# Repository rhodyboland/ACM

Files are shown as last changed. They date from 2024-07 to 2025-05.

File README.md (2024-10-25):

# ACM V2
**Second generation of the ACM**

This device is intended to be a control module for accessories that have been fitted to a camping/touring/4wdriving oriented vehicle. These controllable accessories could be lighting, fridge, air commpressor, water pump, tv, and more. 
The device can take inputs from various sources and use internal logic to provide monitoring to the user.
The device is to be app controlled from a mobile phone.

### Hardware:
  - 3rd generation of custom PCB with high side switches from STM. Powered by ESP32-S3
    - STM High side switches with current sensing and auto disconnect
      - 2x VNQ9025AJTR Quad Channel 30A max
      - 1x VND9008AJTR Dual Channel 67A max
  - RGB LED WS2812B
  - ESP32-S3-WROOM1-N16R8
      - USB C Programming and debug
      - Reset and boot buttons
      - Auto selecting 12v or USB 5v 3v3 regulator
  - Inputs for 2 sensors and 2 12v switches/inputs
  - Outputs Term blocks
  - High current 12V input
  - CAN for expansion

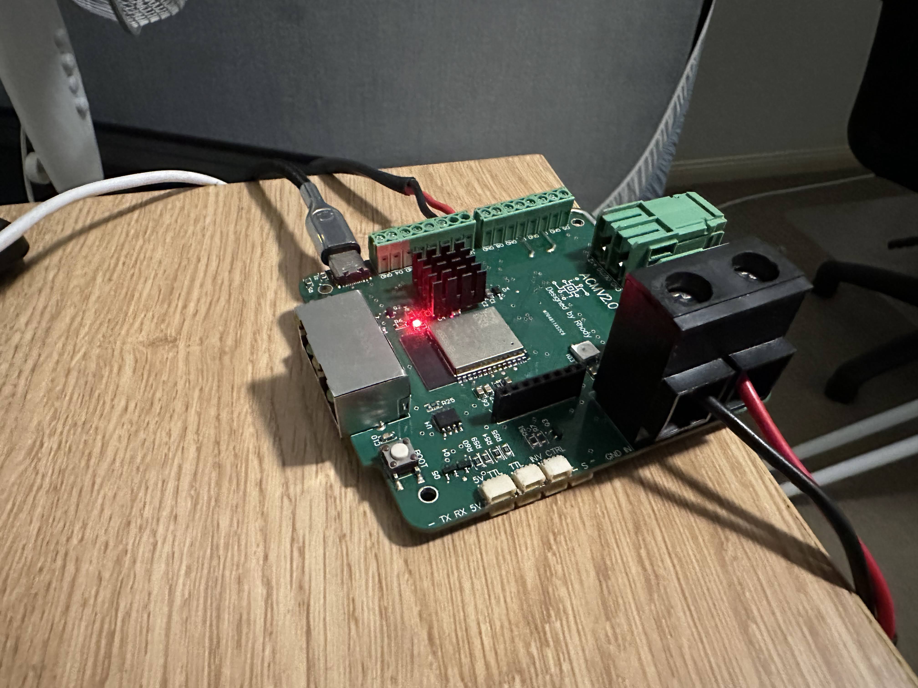
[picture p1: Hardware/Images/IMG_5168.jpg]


### Software:
#### Platform IO using arduino framework
  - BLE
#### Features (configurable in app)
- Switches for each channel
- Battery voltage and percentage
- Total and individual current measurement
- Auto cut-out of outputs for low battery voltage with priority selection and auto cut-in
- Power used and remaining
- Victron VE Serial input and parsing (MPPT etc.)
- JK BMS input.
- Low side switched inverter control (Highside uses standard out)
- Diagnostic outputs
- CAN to esp32 display coming

#### Custom IOS App ####

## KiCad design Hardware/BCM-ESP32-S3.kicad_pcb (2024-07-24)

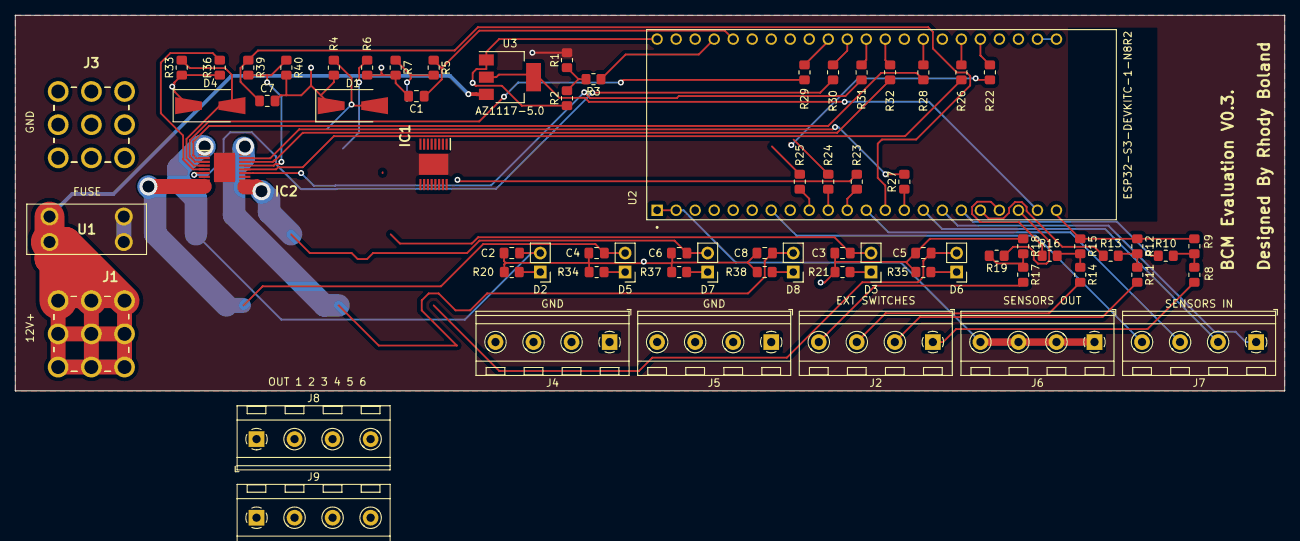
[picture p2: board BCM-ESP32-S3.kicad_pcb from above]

Board: 2 copper layers, 169.5 x 50.2 mm, 70 parts (0 on the bottom side), 65 nets.

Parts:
C1, C2, C3, C4, C5, C6, C7, C8: 10nF; C_0805_2012Metric_Pad1.18x1.45mm_HandSolder
D1, D4: ES1DL; D_SMA-SMB_Universal_Handsoldering
D2, D3, D5, D6, D7, D8: LED; PinHeader_1x02_P2.54mm_Vertical
IC1: VND9012AJ; SOP50P600X170-17N
IC2: VNQ9080AJTR; SOP50P600X170-17N
J1: 12V+ Terminal; 74650194R
J2, J8, J9: EXT SWITCHES; TerminalBlock_RND_205-00234_1x04_P5.08mm_Horizontal
J3: GND Terminal; 74650194R
J4, J5: GND; TerminalBlock_RND_205-00234_1x04_P5.08mm_Horizontal
J6: SENSORS OUT; TerminalBlock_RND_205-00234_1x04_P5.08mm_Horizontal
J7: SENSORS IN; TerminalBlock_RND_205-00234_1x04_P5.08mm_Horizontal
R1, R5, R6, R8, R11, R14, R17, R22, R23, R24, R25, R26, R27, R28, R29, R30, R31, R32, R36, R39: 15K; R_0805_2012Metric_Pad1.20x1.40mm_HandSolder
R2, R4, R9, R12, R15, R18, R33: 4K7; R_0805_2012Metric_Pad1.20x1.40mm_HandSolder
R3, R7, R10, R13, R16, R19, R40: 1K; R_0805_2012Metric_Pad1.20x1.40mm_HandSolder
R20, R21, R34, R35, R37, R38: 2K2; R_0805_2012Metric_Pad1.20x1.40mm_HandSolder
U1: 3568
U2: ESP32-S3-DEVKITC-1-N8R2; XCVR_ESP32-S3-DEVKITC-1-N8R2
U3: AZ1117-5.0; SOT-223-3_TabPin2

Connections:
+3V3: J6.1, J6.2, J6.3, J6.4, U2.J1_1 (3V3), U2.J1_2 (3V3)
+5V: U2.J1_21 (5V0), U3.2 (VO)
+12V: IC1.17 (VCC), IC2.17 (VCC), R1.2, U1.3, U1.4
/Dual_CS: C1.1, R5.1, U2.J3_5 (GPIO2)
/Dual_INPUT0: IC1.1 (INPUT0), R25.2
/Dual_INPUT1: IC1.8 (INPUT1), R24.2
/Dual_SEL: IC1.5 (SEL), R23.2
/Dual_SEN: IC1.3 (SEn), R22.2
/EXT0: R10.1, U2.J1_17 (GPIO11)
/EXT1: R13.1, U2.J1_18 (GPIO12)
/EXT2: R16.1, U2.J1_19 (GPIO13)
/EXT3: R19.1, U2.J1_20 (GPIO14)
/EXT_SWITCH0: J2.1, R8.2
/EXT_SWITCH1: J2.2, R11.2
/EXT_SWITCH2: J2.3, R14.2
/EXT_SWITCH3: J2.4, R17.2
/OUT0: C2.1, D2.2 (A), IC2.1 (OUTPUT0), J8.1
/OUT1: C4.1, D5.2 (A), IC2.8 (OUTPUT1), J8.2
/OUT2: C6.1, D7.2 (A), IC2.9 (OUTPUT2), J8.3
/OUT3: C8.1, D8.2 (A), IC2.16 (OUTPUT3), J8.4
/OUT4: C3.1, D3.2 (A), IC1.13 (OUTPUT0), IC1.14 (OUTPUT0), IC1.15 (OUTPUT0), IC1.16 (OUTPUT0), J9.1
/OUT5: C5.1, D6.2 (A), IC1.9 (OUTPUT1), IC1.10 (OUTPUT1), IC1.11 (OUTPUT1), IC1.12 (OUTPUT1), J9.2
/Quad_CS: C7.1, R39.1, U2.J1_13 (GPIO3)
/Quad_INPUT0: IC2.3 (INPUT0), R29.2
/Quad_INPUT1: IC2.6 (INPUT1), R30.2
/Quad_INPUT2: IC2.11 (INPUT2), R31.2
/Quad_INPUT3: IC2.14 (INPUT3), R32.2
/Quad_SEL0: IC2.12 (SEL0), R26.2
/Quad_SEL1: IC2.15 (SEL1), R27.2
/Quad_SEN: IC2.2 (SEN), R28.2
/VBAT_ADC: R3.1, U2.J3_4 (GPIO1)
GND: C1.2, C2.2, C3.2, C4.2, C5.2, C6.2, C7.2, C8.2, D1.1 (K), D4.1 (K), J3.1, J3.2, J3.3, J3.4, J3.5, J3.6, J3.7, J3.8, J3.9, J4.1, J4.2, J4.3, J4.4, J5.1, J5.2, J5.3, J5.4, R2.1, R4.1, R6.1, R7.2, R9.1, R12.1, R15.1, R18.1, R20.1, R21.1, R33.1, R34.1, R35.1, R36.1, R37.1, R38.1, R40.2, U2.J1_22 (GND), U2.J3_1 (GND), U2.J3_21 (GND), U2.J3_22 (GND), U3.1 (GND)
unnamed: D1.2 (A), IC1.4 (GND), R4.2
unnamed: D2.1 (K), R20.2
unnamed: D3.1 (K), R21.2
unnamed: D4.2 (A), IC2.4 (GND), R33.2
unnamed: D5.1 (K), R34.2
unnamed: D6.1 (K), R35.2
unnamed: D7.1 (K), R37.2
unnamed: D8.1 (K), R38.2
unnamed: IC1.7 (CS), R5.2, R7.1
unnamed: IC1.2 (FaultRST), R6.2
unnamed: IC2.13 (CS), R39.2, R40.1
unnamed: IC2.5 (~FAULTRST), R36.2
unnamed: J7.1, U2.J1_16 (GPIO10)
unnamed: J7.2, U2.J1_15 (GPIO9)
unnamed: J7.3, U2.J1_12 (GPIO8)
unnamed: J7.4, U2.J1_7 (GPIO7)
unnamed: R1.1, R2.2, R3.2
unnamed: R8.1, R9.2, R10.2
unnamed: R11.1, R12.2, R13.2
unnamed: R14.1, R15.2, R16.2
unnamed: R17.1, R18.2, R19.2
unnamed: R25.1, U2.J1_9 (GPIO16)
unnamed: R24.1, U2.J1_10 (GPIO17)
unnamed: R23.1, U2.J1_11 (GPIO18)
unnamed: R22.1, U2.J3_18 (GPIO21)
unnamed: R32.1, U2.J3_13 (GPIO35)
unnamed: R31.1, U2.J3_12 (GPIO36)
unnamed: R30.1, U2.J3_11 (GPIO37)
unnamed: R29.1, U2.J3_10 (GPIO38)
unnamed: R28.1, U2.J3_15 (GPIO45)
unnamed: R27.1, U2.J1_14 (GPIO46)
unnamed: R26.1, U2.J3_17 (GPIO47)
unnamed: J1.1, J1.2, J1.3, J1.4, J1.5, J1.6, J1.7, J1.8, J1.9, U1.1, U1.2, U3.3 (VI)

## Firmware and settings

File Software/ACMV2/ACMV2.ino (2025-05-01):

#include <Wire.h>
#include <Adafruit_MCP23X17.h>
#include <SPI.h>
#include <BLEDevice.h>
#include <BLEServer.h>
#include <BLEUtils.h>
#include <BLE2902.h>

// ----- Constants and Definitions -----
#define RGB_BRIGHTNESS 255 // Default brightness for the RGB LED
#define V_SENSE 2          // Pin for voltage sensing

// ----- ESP32 OUTPUTS -----
#define LC1 17
#define LC2 18
#define LC3 19
#define LC4 35
#define LC5 36
#define LC6 37
#define LC7 38
#define LC8 39
#define MC1 40
#define MC2 41

// ----- SPI IO-Expander MCP23S17 OUTPUTS -----
#define MCP_ChipSelect 10
#define Q1_SEn 0
#define Q1_SEL0 1
#define Q1_SEL1 2
#define Q1_RST 3
#define Q2_SEn 4
#define Q2_SEL0 5
#define Q2_SEL1 6
#define Q2_RST 7
#define D_SEn 8
#define D_SEL 9
#define D_RST 10
#define INV_CTRL 15

// ----- ESP32 INPUTS -----
#define INV_STATE 1
#define Q1_CS 3
#define Q2_CS 4
#define D_CS 5
#define SENSE_1 6
#define thermisterSeriesRes 9880

#define SENSE_2 7
#define EXT_SW1 42
#define EXT_SW2 45


// ----- I/O -----
#define SPARE1 14
#define SPARE2 15
#define SPARE3 16

// USART 1 5V (Victron)
#define U1_RX 8
#define U1_TX 9

// USART 2 3v3 (JK BMS)
#define U2_RX 46
#define U2_TX 47

// CAN SN65HVD230DR
#define CAN_TX 20
#define CAN_RX 21

// MCP23S17 Setup
Adafruit_MCP23X17 mcp;

// ----- BLE Definitions -----
#define SERVICE_UUID        "4fafc201-1fb5-459e-8fcc-c5c9c331914b"
#define CHARACTERISTIC_UUID "beb5483e-36e1-4688-b7f5-ea07361b26a8"

BLECharacteristic *pCharacteristic;
bool deviceConnected = false;
bool oldDeviceConnected = false;

// Configuration and Status Variables
float critVoltage = 10.0;
float cutOutVoltage = 11.0;
float cutInVoltage = 11.5;
bool autoCutoffEnabled = true;
bool alwaysOnChannels[10] = {false, false, false, false, false, false, false, false, false, false};
bool priorityChannels[10] = {false, false, false, false, false, false, false, false, false, false}; // Priority channels
bool lowCurrentStates[8] = {false, false, false, false, false, false, false, false};
bool mediumCurrentStates[2] = {false, false};
int lowCurrentBrightness[8] = {255, 255, 255, 255, 255, 255, 255, 255};

// Voltage divider ratio and calibration factor for voltage sensing
const float voltageDividerRatio = 5.68;
const float voltageCalibrationFactor = 1.021;

// Rolling average buffer for voltage readings
const int voltageBufferSize = 10;
float voltageBuffer[voltageBufferSize] = {0.0};
int voltageBufferIndex = 0;
unsigned long lastVoltageReadMillis = 0; // Last voltage read timestamp

const int currentBufferSize = 10; // Rolling average size for current values

// Buffers to store last 10 current readings for each channel
float lowCurrentBuffers[8][currentBufferSize] = {0};
int lowCurrentIndex[8] = {0};

// Buffers to store last 10 current readings for each medium current channel
float mediumCurrentBuffers[2][currentBufferSize] = {0};
int mediumCurrentIndex[2] = {0};

bool errorPresent = false;
int errorCode = 0;
bool outputsDisabled = false;
float batteryVoltage = 0; // This is the main voltage we feed into the system
float totalCurrent = 0;

float sensor1 = 0;

// Maximum block size to prevent buffer overflow
#define MAX_BLOCK_SIZE 512

// Buffer to store incoming block data
char blockBuffer[MAX_BLOCK_SIZE];
int blockIndex = 0;

// Watchdog variables (for Victron)
unsigned long lastSerialDataMillis = 0; 
const unsigned long WATCHDOG_TIMEOUT = 3000; 
bool serialConnectionActive = false; // Flag for Victron connection

// ----- Victron Fields -----
unsigned int PID; // Product ID
unsigned int FW;  // Firmware version
String SER_num;   // Serial number
int V;            // main battery voltage
int I;            // main battery current
int VPV;          // panel voltage (mV)
int PPV;          // Panel Power (W)
int CS;           // Current state (of operation)
unsigned long OR; // Off reason
int ERR;          // Error code
String LOAD_state;// Load state (ON/OFF)
int IL;           // Load Current (mA)
int H19;          // Yield total (0.01kWh)
int H20;          // Yield today (0.01kWh)
int H21;          // Max power today (W)
int H22;          // Yield Yesterday (0.01kWh)
int H23;          //Max power yesterday (W)
int HSDS;         // Day sequence number (0-364)

// Enum to manage reading states
enum State { 
  READING_LINES,
  BLOCK_COMPLETE
};
State currentState = READING_LINES;

// Temporary storage for the current line being read
String currentLine = "";
uint32_t checksumSum = 0;

// ----------------------------------------------------------------------
// JK-BMS Integration
// ----------------------------------------------------------------------
HardwareSerial SerialBMS(2);  // Use UART #2 on ESP32-S3

// Full request frame for JK-BMS:
static const uint8_t JK_BMS_REQUEST[] = {
  0x4E, 0x57, 0x00, 0x13, 0x00, 0x00, 0x00, 0x00,
  0x06, 0x03, 0x00, 0x00, 0x00, 0x00, 0x00, 0x00,
  0x68, 0x00, 0x00, 0x01, 0x29
};

// We read up to 512 bytes from BMS
uint8_t bmsBuf[512];
uint16_t bmsLen = 0;
unsigned long lastBmsDataMillis = 0;
bool bmsConnected = false; // Flag for BMS connection

// BMS data
float bmsVoltage = -1.0f;
float bmsCurrent = 0.0f;
float bmsPower   = 0.0f;
uint8_t bmsSoc   = 0;
// We parse up to 4 cells for demonstration
float cellVoltages[4] = {0,0,0,0};
float avgCellVoltage   = 0.0f;
int16_t mosTemp        = -999;
int16_t batTemp1       = -999;
int16_t batTemp2       = -999;

// Helper: read for up to `timeoutMs` from BMS
uint16_t readBmsFrame(uint16_t timeoutMs) {
  uint16_t idx = 0;
  unsigned long start = millis();
  while (millis() - start < timeoutMs) {
    while (SerialBMS.available()) {
      if (idx < 512) {
        bmsBuf[idx++] = SerialBMS.read();
      } else {
        // overflow discard
        SerialBMS.read();
      }
      start = millis(); // reset timeout
    }
  }
  return idx;
}

// Read a 16-bit big-endian integer from buf[offset..offset+1]
uint16_t readU16BE(const uint8_t *buf) {
  return (uint16_t(buf[0]) << 8) | buf[1];
}

// Convert JK “raw temperature” to signed degrees C
int16_t convertJKTemperature(uint16_t rawVal) {
  if (rawVal <= 100) return rawVal;
  return rawVal - 200; 
}

// Current: top bit => charge vs discharge, rest => x0.1A
float convertJKCurrent(uint16_t rawValBE) {
  bool isCharge = (rawValBE & 0x8000) != 0;
  uint16_t magnitude = (rawValBE & 0x7FFF);
  float amps = magnitude * 0.01f;
  return isCharge ? amps : -amps;
}

bool parseBmsFrame(const uint8_t *buf, uint16_t len) {
  if (len < 10) return false;
  if (buf[0] != 0x4E || buf[1] != 0x57) return false;
  // For demonstration, parse these tokens: 0x79 (cells), 0x80..82 temps, 0x83 volt, 0x84 current, 0x85 SOC
  // We'll reset them each parse:
  for (int c = 0; c < 4; c++) cellVoltages[c] = 0.0f;
  avgCellVoltage = 0.0f;
  bmsVoltage = -1.0f;
  bmsCurrent = 0.0f;
  bmsPower   = 0.0f;
  bmsSoc     = 0;
  mosTemp    = -999;
  batTemp1   = -999;
  batTemp2   = -999;

  uint16_t i = 0;
  while (i + 1 < len) {
    uint8_t token = buf[i];
    if (token == 0x79 && i + 1 < len) {
      uint8_t blockSize = buf[i+1];
      uint16_t needed = i + 2 + blockSize;
      if (needed > len) break;

      uint8_t cellCount = blockSize / 3; 
      float sumC = 0.0f;
      for (uint8_t c=0; c<cellCount && c<4; c++) {
        uint16_t off = i + 2 + c*3;
        // [cellIndex, hiVolt, loVolt]
        uint16_t mv = (buf[off+1]<<8) | buf[off+2];
        float cv = mv * 0.001f;
        cellVoltages[c] = cv;
        sumC += cv;
      }
      if (cellCount > 0) {
        avgCellVoltage = sumC / cellCount;
      }
      i = needed;
    }
    else if (token == 0x80 && i+2 < len) {
      uint16_t rawT = readU16BE(&buf[i+1]);
      mosTemp = convertJKTemperature(rawT);
      i += 3;
    }
    else if (token == 0x81 && i+2 < len) {
      uint16_t rawT = readU16BE(&buf[i+1]);
      batTemp1 = convertJKTemperature(rawT);
      i += 3;
    }
    else if (token == 0x82 && i+2 < len) {
      uint16_t rawT = readU16BE(&buf[i+1]);
      batTemp2 = convertJKTemperature(rawT);
      i += 3;
    }
    else if (token == 0x83 && i+2 < len) {
      uint16_t raw10mV = readU16BE(&buf[i+1]);
      bmsVoltage = raw10mV * 0.01f;
      i += 3;
    }
    else if (token == 0x84 && i+2 < len) {
      uint16_t rawCur = readU16BE(&buf[i+1]);
      bmsCurrent = convertJKCurrent(rawCur);
      i += 3;
    }
    else if (token == 0x85 && i+1 < len) {
      bmsSoc = buf[i+1];
      i += 2;
    }
    else {
      i++;
    }
  }

  bmsPower = bmsVoltage * bmsCurrent;

  // Mark success if we at least have a voltage > 0
  if (bmsVoltage > 0.0f) {
    return true;
  }
  return false;
}

float readInverterVoltage() {
    // Example: If INV_STATE is an analog-capable pin
    // Adjust the ADC range, voltage reference, and scaling as needed
    int rawValue = analogRead(INV_STATE);
    float measuredVoltage = (rawValue * 3.3f / 4095.0f); // For ESP32 12-bit ADC
    return measuredVoltage;
}

// Poll the JK-BMS, read & parse data
void pollBms() {
  // 1) Clear leftover
  while (SerialBMS.available()) {
    SerialBMS.read();
  }
  // 2) Send the full request
  SerialBMS.write(JK_BMS_REQUEST, sizeof(JK_BMS_REQUEST));
  // 3) Wait & read
  uint16_t length = readBmsFrame(1000); 
  if (length == 0) {
    // No data => possibly disconnected
    return;
  }
  if (parseBmsFrame(bmsBuf, length)) {
    bmsConnected = true;
    lastBmsDataMillis = millis();
  }
}



// ----------------------------------------------------------------------
// Function Prototypes from Original Code
// ----------------------------------------------------------------------
void setLEDColor(char color);
void flashLED(char color, int times, int delayTime);
void pulseLED(char color, int pulseDuration);
void handleAutoShutdownWarning();
void checkBatteryVoltage();
void handleConnectionIndicator();
void handleCommandReceivedIndicator();
void handleErrorIndicator(int errorCode);
void disableOutputs();
void manageErrorState();
float readRealVoltage();
void sendSensorData();
int getLowCurrentPin(int index);
int getMediumCurrentPin(int index);
float readQuadCurrent(int channel, int selectPin, int sensePin);
float readDualCurrent(int channel);
void applyConfiguration(const std::string &config);

// ----------------------------------------------------------------------
// BLE Setup
// ----------------------------------------------------------------------
class MyCallbacks : public BLEServerCallbacks {
    void onConnect(BLEServer* pServer) {
        deviceConnected = true;
        handleConnectionIndicator(); // New device connected
    }
    void onDisconnect(BLEServer* pServer) {
        deviceConnected = false;
        BLEDevice::startAdvertising();
        flashLED('R', 1, 250); // Device disconnected
    }
};
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
void loop() {
    // 1) Poll the JK-BMS ~every 1s
    static unsigned long lastBmsPoll = 0;
    if (millis() - lastBmsPoll >= 1000) {
      lastBmsPoll = millis();
      pollBms();
      getSensor();
    }
    // If we haven't received new BMS data in >3s, mark bmsConnected false
    if (bmsConnected && (millis() - lastBmsDataMillis > 3000)) {
      bmsConnected = false;
    }

    // 2) Check battery voltage logic
    checkBatteryVoltage(); 
    manageErrorState();
    

    // 3) Process Victron Serial (Serial1) data
    while (Serial1.available()) {
        char incomingByte = Serial1.read();
        checksumSum += static_cast<unsigned char>(incomingByte);
        // Serial.println(incomingByte);
        if (blockIndex < MAX_BLOCK_SIZE - 1) {
            blockBuffer[blockIndex++] = incomingByte;
            lastSerialDataMillis = millis();
            serialConnectionActive = true;
        } else {
            Serial.println("Error: Block buffer overflow");
            blockIndex = 0;
            checksumSum = 0;
            currentLine = "";
            return;
        }

        if (incomingByte == '\n') {
            if (currentLine.endsWith("\r")) {
                currentLine.remove(currentLine.length() - 1);
            }
            // Check for "Checksum" line
            if (currentLine.startsWith("Checksum\t")) {
                if ((checksumSum % 256) == 0) {
                    blockBuffer[blockIndex] = '\0';
                    parseVictronBlock(blockBuffer);
                } else {
                    Serial.println("Error: Checksum invalid");
                }
                blockIndex = 0;
                checksumSum = 0;
            } 
            currentLine = "";
        } else {
            currentLine += incomingByte;
        }
    }
    // Watchdog for Victron
    if (millis() - lastSerialDataMillis > WATCHDOG_TIMEOUT) {
        if (serialConnectionActive) {
            serialConnectionActive = false;
            Serial.println("Watchdog: No serial data received for 3 seconds.");
        }
    }
}

// ----------------------------------------------------------------------
// Adjusted checkBatteryVoltage: uses BMS if connected, else fallback
// ----------------------------------------------------------------------
void checkBatteryVoltage() {
    unsigned long currentMillis = millis();
    if (currentMillis - lastVoltageReadMillis >= 100) {
        lastVoltageReadMillis = currentMillis;

        // If we have BMS data, use it. Otherwise, read from the voltage divider
        if (bmsConnected && bmsVoltage > 0.0f) {
          batteryVoltage = bmsVoltage;
        } else {
          batteryVoltage = readRealVoltage();
        }
    }

    if (batteryVoltage < critVoltage) {
        handleAutoShutdownWarning();
    } else if (batteryVoltage < cutOutVoltage + 0.2) {
        flashLED('Y', 3, 500);
    } else if (batteryVoltage < cutOutVoltage && !outputsDisabled) {
        disableOutputs();
    } else if (batteryVoltage >= cutInVoltage && outputsDisabled) {
        outputsDisabled = false;
        setLEDColor('G');
    }
    // Now enforce Always-On & Priority channels here:
    updateChannels();
}

// ----------------------------------------------------------------------
// Update sendSensorData to include BMS connectivity & values
// ----------------------------------------------------------------------
String floatToHex(float value, int scale);
String stateToHex(bool state);

void sendSensorData() {
    // If bmsConnected => use BMS current for BLE or keep your existing logic?
    // We'll just share BMS current in a new field. Or you can do whatever you want.

    // In your original code, you assemble voltageCurrentSection with:
    //   batteryVoltage (from the global), totalCurrent, solarVoltage, solarCurrent, ...
    // We'll add the BMS connect flag similarly to how we do "connectionFlag" for victron.
    float inverterVoltage = readInverterVoltage();
    // Voltage & Current:
    String batteryVoltageHex = floatToHex(batteryVoltage, 100);
    String cellAvgHex = floatToHex(avgCellVoltage, 100);
    // totalCurrent is from readQuadCurrent & readDualCurrent sums
    // bmsCurrent is A*10 ie -4 A -> 40.00
    String currentUsageBMSHex = floatToHex(bmsCurrent + 512, 10);
    // Serial.println(bmsCurrent);
    String currentUsageHex = floatToHex(totalCurrent, 100);
    // Solar from your code:
    String solarVoltageHex = floatToHex(VPV, 100);
    String solarCurrentHex = floatToHex(I, 100);
    String solarPowerHex = floatToHex(PPV, 100);
    String solarStateHex = floatToHex(CS, 1);
    Serial.println(bmsCurrent);

    String batTemp1Hex = floatToHex(batTemp1, 100);

    String batSocHex = floatToHex(bmsSoc, 100);
    // Serial.println(sensor1);
    String sensor1Hex = floatToHex(sensor1, 100);

    // Convert to a hex string (scaled by 100, for example)
    String inverterHex = floatToHex(inverterVoltage, 100);

    // Victron connection flag:
    String connectionFlag = serialConnectionActive ? "1" : "0";
    // Serial.println(serialConnectionActive);

    // **Add BMS flag**:
    String bmsFlag = bmsConnected ? "1" : "0";

    // Combine in the voltageCurrentSection
    // We'll add bmsFlag at the end
    String voltageCurrentSection = "V:" + batteryVoltageHex + "," + currentUsageBMSHex + "," + currentUsageHex + "," 
                                     + solarVoltageHex + "," + solarCurrentHex + "," 
                                     + solarPowerHex + "," + solarStateHex + "," + cellAvgHex  + "," + batTemp1Hex + "," + batSocHex + "," + sensor1Hex + "," 
                                     + connectionFlag + "," + bmsFlag + ";" ;

    // Low current channels
    String loadChannelsSection = "L:";
    for (int i = 0; i < 8; i++) {
        String stateHex = stateToHex(lowCurrentStates[i]);
        String brightnessHex = String(lowCurrentBrightness[i], HEX);
        float current = (i < 4) ? readQuadCurrent(i, Q1_SEL0, Q1_CS) 
                                : readQuadCurrent(i - 4, Q2_SEL0, Q2_CS);
        String currentHex = floatToHex(current, 1000);
        loadChannelsSection += stateHex + brightnessHex + currentHex + ((i < 7) ? "," : ";");
    }

    // Medium current channels
    String mediumChannelsSection = "M:";
    for (int i = 0; i < 2; i++) {
        String stateHex = stateToHex(mediumCurrentStates[i]);
        float current = readDualCurrent(i);
        String currentHex = floatToHex(current, 1000);
        mediumChannelsSection += stateHex + currentHex + ((i < 1) ? "," : ";");
    }

    
    // Add an inverter section to the data packet, e.g. "I:0FA6;"
    // (whatever formatting you prefer)
    String inverterSection = "I:" + inverterHex + ";";


    // Combine all sections
    String dataPacket = voltageCurrentSection + loadChannelsSection + mediumChannelsSection + inverterSection;
    totalCurrent = 0; // Reset after each send

    pCharacteristic->setValue(dataPacket.c_str());
    pCharacteristic->notify();

    Serial.println("Data sent: " + dataPacket);
}

// Helper for hex conversions
String floatToHex(float value, int scale) {
    return String((int)(value * scale), HEX);
}
String stateToHex(bool state) {
    return state ? "1" : "0";
}

// ----------------------------------------------------------------------
// The rest are your original utility functions
// ----------------------------------------------------------------------
void disableOutputs() {
    for (int i = 1; i <= 8; i++) {
        digitalWrite(getLowCurrentPin(i), LOW);
    }
    for (int i = 1; i <= 2; i++) {
        digitalWrite(getMediumCurrentPin(i), LOW);
    }
    outputsDisabled = true;
    flashLED('R', 3, 300);
}

void handleAutoShutdownWarning() {
    pulseLED('R', 1000);
}

void setLEDColor(char color) {
    // Placeholder for your neopixelWrite or LED code
    // e.g. neopixelWrite(RGB_BUILTIN, r, g, b)
}

void flashLED(char color, int times, int delayTime) {
    for (int i = 0; i < times; i++) {
        setLEDColor(color);
        delay(delayTime);
        setLEDColor('O');
        delay(delayTime);
    }
}

void pulseLED(char color, int pulseDuration) {
    // Basic example
    for (int i = 0; i < RGB_BRIGHTNESS; i++) {
        // e.g. neopixelWrite(RGB_BUILTIN, i,0,0) if color=='R'
        delay(pulseDuration / RGB_BRIGHTNESS);
    }
    for (int i = RGB_BRIGHTNESS; i >= 0; i--) {
        // ...
        delay(pulseDuration / RGB_BRIGHTNESS);
    }
}

void handleConnectionIndicator() {
    flashLED('G', 1, 250);
}

void handleCommandReceivedIndicator() {
    flashLED('B', 1, 250);
}

void handleErrorIndicator(int code) {
    errorCode = code;
    errorPresent = true;
    manageErrorState();
}
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

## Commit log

2024-07-24 Migration to git. Add existing software and hardware files relevent to V1 (0.3).
    [BCM-ESP32-S3-B_Cu.gbr, BCM-ESP32-S3-B_Mask.gbr, BCM-ESP32-S3-B_Paste.gbr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]
2024-09-26 Updates to current measurment, averages current for each channel, other minor updates
2024-10-25 New PCB photo
2025-01-11 Implement inverter control, other stability changes
    [ACMV2.ino]
2025-03-10 Include support for a temp sensor, add JK_BMS serial support
2025-05-01 Fix victron and bms current sending. Allows negatives.
    [ACMV2.ino]
